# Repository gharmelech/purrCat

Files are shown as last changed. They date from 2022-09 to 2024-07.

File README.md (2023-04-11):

# **purrCat**

This is a novelty PCB Art of a purring cat.

Feel free to use this project or parts of it at will, but please give credit when doing so.

While this is an open source project, I am selling kits and assembled units for 10 and 15 USD respectivly.  
Please consider supporting us by [ordering here](https://forms.gle/wS7aRQJ3xb9KGsVB8).

## **Art**
The art was made by Taly Reznik - [@trollworks](https://www.instagram.com/trollworks/?fbclid=IwAR2XS3pt9mpKQIKOb-wqeVHk0iGZXp5bulvpvjSy-UH8qeWS0hPnVhlgy5U)  
Go check out her awesome work!

## **Hardware Description**
The project is based on TI's msp430fr2111 MCU. The current software could fit in (and easily compiled for) msp430fr2110 and could probably be further optimized to fit msp430fr2100, but going with the 2111 model leaves a lot of room for future expansion with just a small price difference.  

Purring is achived with a round radial vibration motor, which is low-side controlled with an nmos transistor.  
In addition, the eyes light up using reverse-mounted LEDs (might be worthwhile to change it to a side view LED in the future).  

Petting is detected using capacitive touch.  
There are 4 touch pads on the PCB, but only 1 is in use in the current FW.

### **Some FW details**

#### **Picky Cat!**
I wanted to make the cat as realistic as possible, so it only likes petting between 0.5 and 2Hz.  
(*Since I'm not doing swipe detection, it would also work with tapping. I might change it in a future version*)  
This is achived using a 2s sample buffer with 125ms slots. if the pad is touched for more than 3 slots in a row, the buffer zeroes.  
Furthermore, purring only starts after at least 1s of petting.

#### **Realistic Purring**
I have programmed a simple PWM function to make the vibration feel like real purring.  
It has dynamic change to the duty cycle, this creates the subtle ramp-up and ramp-down typical of a cat's purring.  
I tried a sinusoidal PWM function, but it didn't have the right feel to it.

#### **Programming and flashing**
The MCU is programmed using Code Composer Studio IDE.  
For software flashing I use a TI dev board LAUNCHPAD MSP-EXP430FR2433, which is the lowest cost programmer option available, though I assume you could make a flashing device out of an arduino.  
I left 3x2mm pitch pads for programming right near the MCU.  
They are arranged (from top to bottom) GND-SBWTCK-SBWTDIO, an additional connection to VCC is required and could be obtained from the battery clip.

### **Power Consumption**
The FW used to feature a distinct power saving mode, but changing the wait timer to RTC with VLO clock source randered that mode as unnedded.  
It is still available in code using a #define flag.

In the current configuration, sampling consumes about 2 micro Ampere - around 60uW at nominal 3V.  
When Purring, i.e. when the motor and the LEDs are enabled, the current consumption is about 22mA - 66mW at nonminal 3V.

The final design uses a cr2032 lithium cell which are rated at about 240mAh.  
While theoretical battery life should have been roughly 8 hours of purring or about 6 years of idle,  
The 240mAh rating is given at much lower current draw than that of the active purring.  
At 20mA, most cr2032 have a capacity of a mere 10-15mAh, giving only about 30 minutes of active purring.

I don't have a good explantion for it, but idle time also seems to substencialy lower than the theoretical - getting to around one week.

Note that this is not linear and even a small reduction in current draw while purring would result in longer operation time.  
Sadly, I was'nt able to find a way to reduce to consumption enough.

#### **LiPo mod**
Giving the poor battery life, I designed a small PCB holding an LDO and a charge connector for a LiPo, to be soldered instead of the battery clip.
The thought of using a LiPo crossed my mind several times, but I deemed it unvaiabel because of cost and required PCB space for a charge controller.
Finally, I had the realization to use a generic LiPo charger externaly (which could be obtained from AliExpress for very cheap) instead of making it onboard.
I did changed the current select resistor on the charger such that the max charge current will be 100 mA - suitable for the tiny LiPo I use.

I decided to use a 501015 60mAh battery.
Because these are rated at 1C, we get a runtime much closer to the theoretical value - about 1.5 hours of purring!
I have used a sub-optimal LDO with 30 uA quiescent current, which becomes the dominant current draw during idle.
I calculated arround 40 days of idle time, but have not ran this long time test yet.

### **Parts List**
- MCU: msp430fr2111
- LED: 2x 0805 LED (reverse mounted, color of your choice)
- Capacitors: 2x0805 10uF MLCC (1 for the MCU and 1 for the Motor), 1x0603 100nF MLCC (for the MCU)
- Resistors: 3x0603 1k Ohm (current limiting for the transistor and the LEDs), 1x0603 100k Ohm (pulldown for the transistor, could be omitted as the driver pin is push-pull)
- Diode: 1x0603 schottky diode (I used Kyocera AVX SD0603S040S0R2)
- Transistor: 1xSOT3 NMOS Transistor (I used Nexperia NXV55UNR)
- Battery clip: 1x Keystone 3034 (cr2032 battery holder), note that not all battery holders can fit in the PCBs footprint)
- Vibration motor: 1x 10mm round radial vibration motor(or smaller), note that there are no pads for soldering it. one lead should be connected to vcc(I used the cap for it) and the other to the transistor drain pin (I made a bigger pad to accomodate this).

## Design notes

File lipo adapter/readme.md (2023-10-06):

The lipo adapter is designed to replace the battery holder
it holds an LDO, connector for an external charger and pads for the lipo

Since it is a very simple board, I designed it using the easyEDA online suite.
I recomend manufacturing it as thin as possiable.

For the LDO, I used TLV74333PDBVR, but a more efficiant model would be preferable

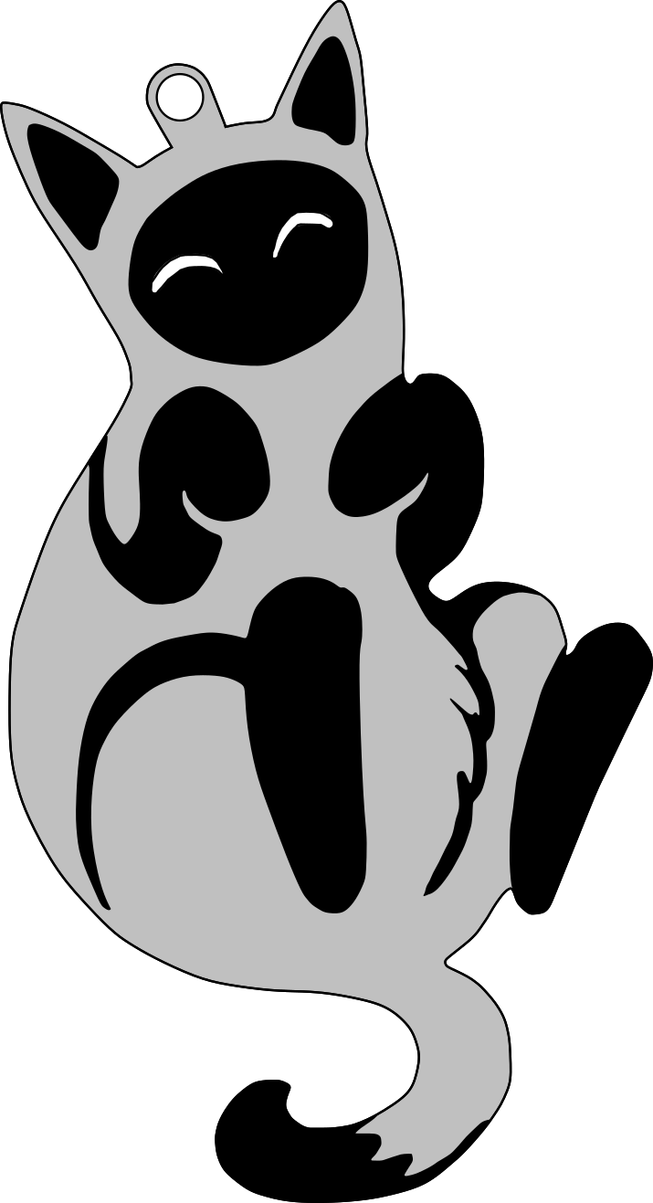
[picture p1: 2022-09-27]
Art/template.png

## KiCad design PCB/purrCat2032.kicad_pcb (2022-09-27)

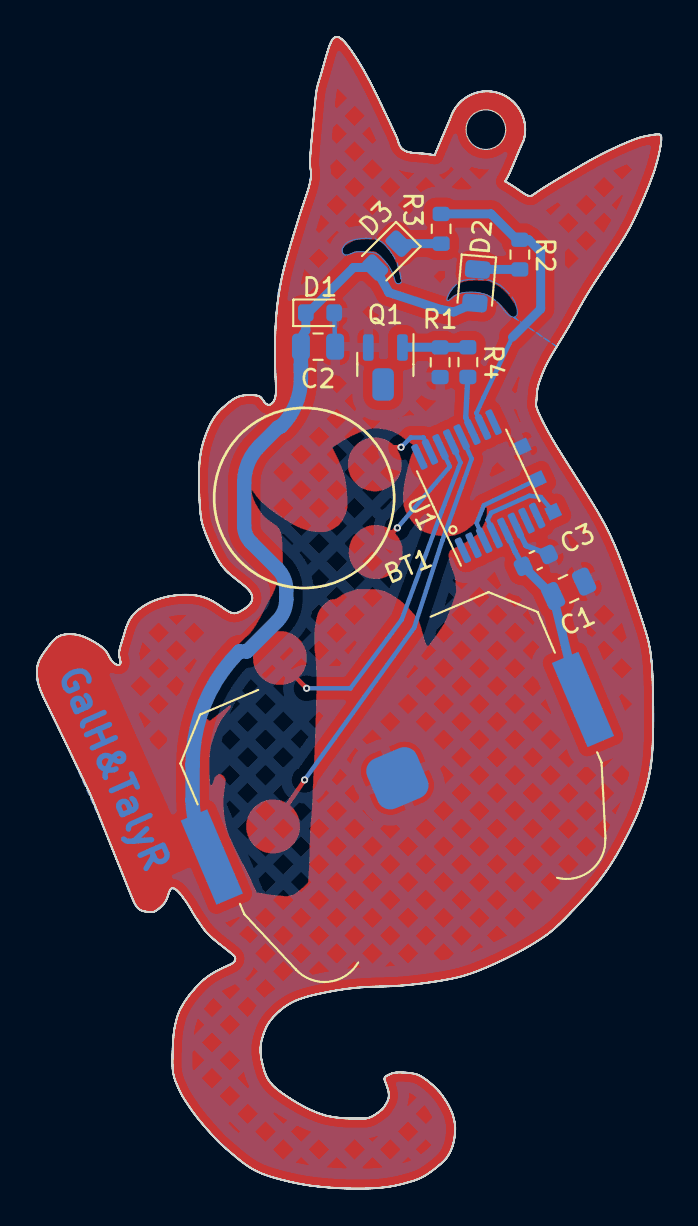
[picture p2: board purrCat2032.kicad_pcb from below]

Board: 2 copper layers, 34.7 x 64.0 mm, 14 parts (13 on the bottom side), 7 nets.

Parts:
BT1: Battery_Cell; BatteryHolder_Keystone_3034_1x20mm
C1, C2: 10u; C_0805_2012Metric
C3: 100n; C_0603_1608Metric
D1: D_Schottky; D_0603_1608Metric
D2, D3: LED; LED_0805_2012Metric
Q1: Q_NMOS_GSD; SOT-23
R1: 100k; R_0603_1608Metric
R2, R3, R4: 1k; R_0603_1608Metric
Ref**: Val**; biggerCat_kicad_layers
U1: MSP430FR2110/MSP430FR2111; TSSOP-16_4.4x5mm_P0.65mm

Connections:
/GND: BT1.2 (-), C1.2, C2.2, C3.2, D1.2 (A), Q1.2 (S), R1.2, U1.6 (DVSS)
/LED1_R: D2.1 (K), R2.1
/LED2_R: D3.1 (K), R3.1
/LED_MCU: R2.2, R3.2, U1.10 (P2.0/TB0.1/COUT)
/MOTOR_MCU: R4.2, U1.11 (P1.7/UCA0TXD/UCA0SIMO/TB0.2/TDO/A7/VREF+)
/MOTOR_MCU_R: Q1.1 (G), R1.1, R4.1
/V_BAT: BT1.1 (+), C1.1, C2.1, C3.1, D1.1 (K), D2.2 (A), D3.2 (A), U1.5 (DVCC)

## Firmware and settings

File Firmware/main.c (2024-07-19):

/*purrCat - a purring cat PCB by Gal Harmelech
 * I wanted to make this cat as picky as a real cat, so it does not purr for any type of petting:
 * The main principle is a 2 seconds buffer with 250 ms slots, this enables identifying "petting" between 0.5 to 4 Hz
 * If being petted with an acceptable pattern for more than 1 second - It will start purring.
 * For the Purring there is a 40 Hz PWM function with 0.25 to 0.33 duty cycle dynamically changing to give the small ramp-up and down in a cat's purring
 * The eyes just light up whenever it is purring, but more sophisticated schemes are possible as the eyes are wired to the second timer output
 * Feel free to improve and expend this software, I'm curious to see what the community could do with it!
 * My one request is that you do not remove my name from it
 * Have Fun!
 * 
 * Some parts of the software are based on TI's example code, for those parts the following is applicable:
 * 
 * --COPYRIGHT--,BSD_EX
 * Copyright (c) 2014, Texas Instruments Incorporated
 * All rights reserved.
 *
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
 * *  Redistributions of source code must retain the above copyright
 *    notice, this list of conditions and the following disclaimer.
 *
 * *  Redistributions in binary form must reproduce the above copyright
 *    notice, this list of conditions and the following disclaimer in the
 *    documentation and/or other materials provided with the distribution.
 *
 * *  Neither the name of Texas Instruments Incorporated nor the names of
 *    its contributors may be used to endorse or promote products derived
 *    from this software without specific prior written permission.
 *
 * THIS SOFTWARE IS PROVIDED BY THE COPYRIGHT HOLDERS AND CONTRIBUTORS "AS IS"
 * AND ANY EXPRESS OR IMPLIED WARRANTIES, INCLUDING, BUT NOT LIMITED TO,
 * THE IMPLIED WARRANTIES OF MERCHANTABILITY AND FITNESS FOR A PARTICULAR
 * PURPOSE ARE DISCLAIMED. IN NO EVENT SHALL THE COPYRIGHT OWNER OR
 * CONTRIBUTORS BE LIABLE FOR ANY DIRECT, INDIRECT, INCIDENTAL, SPECIAL,
 * EXEMPLARY, OR CONSEQUENTIAL DAMAGES (INCLUDING, BUT NOT LIMITED TO,
 * PROCUREMENT OF SUBSTITUTE GOODS OR SERVICES; LOSS OF USE, DATA, OR PROFITS;
 * OR BUSINESS INTERRUPTION) HOWEVER CAUSED AND ON ANY THEORY OF LIABILITY,
 * WHETHER IN CONTRACT, STRICT LIABILITY, OR TORT (INCLUDING NEGLIGENCE OR
 * OTHERWISE) ARISING IN ANY WAY OUT OF THE USE OF THIS SOFTWARE,
 * EVEN IF ADVISED OF THE POSSIBILITY OF SUCH DAMAGE.
 *
 *******************************************************************************
 *
 *                       MSP430 CODE EXAMPLE DISCLAIMER
 *
 * MSP430 code examples are self-contained low-level programs that typically
 * demonstrate a single peripheral function or device feature in a highly
 * concise manner. For this the code may rely on the device's power-on default
 * register values and settings such as the clock configuration and care must
 * be taken when combining code from several examples to avoid potential side
 * effects. Also see www.ti.com/grace for a GUI- and www.ti.com/msp430ware
 * for an API functional library-approach to peripheral configuration.
 *
 * --/COPYRIGHT--*/
//******************************************************************************

#include <msp430.h>
#include <stdint.h>
#include <stdbool.h>

/*Time constants*/
#define WDT_meas_setting (WDT_MDLY_0_5)             // Defines WDT SMCLK interval for sensor measurements with duration of 0.5 ms
#define SAMPLE_PERIOD (125)                         // Time between samples in ms

/*Idle Mode*/
//#define USE_IDLEMODE
#ifdef USE_IDLEMODE
#define ACTIVE_TIME 10                              // Time to stay active before entering idle mode (sec)
#define IDLE_LIMIT (ACTIVE_TIME<<2)
#define IDLE_SAMPLE_PERIOD (1500)                   // Time between samples when in idle mode (ms)
#endif

/* Sensor settings*/
#define KEY_LVL     (750)                           // Defines threshold for a key press
/*Set to ~ half the max delta expected*/

/*Outputs*/
#define LED                 (BIT0)                  // P2.0 LED output
#define MOTOR               (BIT7)                  // P1.7 Vibration motor output

/*Touch Pads*/
#define TOUCHPAD_1          (BIT6)                  // P1.6 Touchpad
#define CAPTURE_TOUCHPAD_1   (CAPTIOEN + CAPTIOPOSEL0 + CAPTIOPISEL_6)
#define TOUCHPAD_2          (BIT5)                  // P1.5 Touchpad
#define CAPTURE_TOUCHPAD_2   (CAPTIOEN + CAPTIOPOSEL0 + CAPTIOPISEL_5)
#define TOUCHPAD_3          (BIT4)                  // P1.4 Touchpad
#define CAPTURE_TOUCHPAD_3   (CAPTIOEN + CAPTIOPOSEL0 + CAPTIOPISEL_4)
#define TOUCHPAD_4          (BIT3)                  // P1.3 Touchpad
#define CAPTURE_TOUCHPAD_4   (CAPTIOEN + CAPTIOPOSEL0 + CAPTIOPISEL_3)

// Global variables for sensing
unsigned int base_cnt, meas_cnt;
int delta_cnt;
uint16_t pressBuffer = 0;
uint8_t outputEnable = 0;
uint8_t dutyCounts [] = {200, 200, 255, 255, 255};
uint8_t dutyIndex = 0;
#ifdef USE_IDLEMODE
uint8_t idleCnt = 0;
#endif
/* System Routines*/
void measure_count(void);                           // Measures each capacitive sensor
void startPWM(void);
void stopPWM(void);

int main(void)
{
    unsigned int i;
    WDTCTL = WDTPW + WDTHOLD;                       // Stop watchdog timer
    SFRIE1 |= WDTIE;                                // enable WDT interrupt
    P1DIR = 0xff;
    P2DIR = 0xff;
    P1OUT = 0x0;
    P2OUT = LED;
    PM5CTL0 &= ~LOCKLPM5;
    __bis_SR_register(GIE);                         // Enable interrupts
    measure_count();                                // Establish baseline capacitance
    base_cnt = meas_cnt;
    for(i=15; i>0; i--)                             // Repeat and avg base measurement
    {
        measure_count();
        base_cnt = (meas_cnt+base_cnt)>>1;
    }
    /* Main loop starts here*/
    while (1)
    {
        pressBuffer = (pressBuffer << 1);           // Advance sliding window
        if (pressBuffer == 0)
            outputEnable = 0;
        measure_count();
        delta_cnt = base_cnt - meas_cnt;            // Calculate delta: c_change
        if (delta_cnt < 0)                          // If negative: result increased
        {                                           // beyond baseline, i.e. cap dec
            base_cnt = (base_cnt+meas_cnt) >> 1;    // Re-average quickly
            delta_cnt = 0;                          // Zero out for pos determination
        }
        else if (delta_cnt > KEY_LVL)               // Touch detected
        {
#ifdef USE_IDLEMODE
            idleCnt = 0;
#endif
            if ((pressBuffer & 0x0006) == 0x0006)   // Two previous slots had a press --> stop output and reset buffer
            {
                pressBuffer = 0;
                outputEnable = 0;
            }
            else
            {
                pressBuffer +=1;                    // push
                if (pressBuffer > 0x7F)
                    outputEnable = 1;
            }
        }
        else                                        // No Touch detected
        {
            base_cnt = base_cnt - 1;                // Account for capacitance drift
#ifdef USE_IDLEMODE
            if (idleCnt < IDLE_LIMIT)
                idleCnt++;
#endif
        }
        if (outputEnable == 1)
        {
            startPWM();
            P2OUT &= (~LED);
        }
        else
        {
            stopPWM();
            P2OUT |= LED;
        }
        RTCMOD = SAMPLE_PERIOD-1;
#ifdef USE_IDLEMODE
        if (idleCnt == IDLE_LIMIT)
            RTCMOD = IDLE_SAMPLE_PERIOD-1;
#endif
        RTCCTL |= RTCSS__VLOCLK | RTCSR |RTCPS__10;
        RTCCTL |= RTCIE;
        __bis_SR_register(LPM4_bits);
    }
}                                                   // End Main

/* Measure count result (capacitance)*/
void measure_count(void)
{
    TB0CTL = TBSSEL_3 + MC_2;                       // INCLK, cont mode
    TB0CCTL1 = CM_3 + CCIS_2 + CAP;                 // Pos&Neg,GND,Cap
    /*Configure Ports for relaxation oscillator*/
    CAPTIOCTL |= CAPTURE_TOUCHPAD_3;                //Only using touchpad #3, in future could create more elaborate functions using the other pads
    /*Setup Gate Timer*/
    WDTCTL = WDT_meas_setting;                      // WDT, ACLK, interval timer
    TB0CTL |= TBCLR;                                // Clear Timer_B TBR
    __bis_SR_register(LPM0_bits+GIE);               // Wait for WDT interrupt
    TB0CCTL1 ^= CCIS0;                              // Create SW capture of CCR1
    meas_cnt = TB0CCR1;                             // Save result
    WDTCTL = WDTPW + WDTHOLD;                       // Stop watchdog timer
    CAPTIOCTL = 0;
}
void startPWM(void)
{
    TB0CCR0 = 900-1;                                // PWM Freq 32.768kHz divided by TB0CCR0
    dutyIndex++;
    if (dutyIndex > 4)
        dutyIndex = 0;
    TB0CCR2 = dutyCounts[(uint8_t)(dutyIndex)];     // CCR2 PWM duty cycle TB0CCR2/TB0CCR0
    TB0CCTL2 = OUTMOD_7;                            // CCR2 reset/set
    TB0CTL = TBSSEL__ACLK | MC__UP | TBCLR;         // ACLK, up mode, clear TAR
    P1SEL1 |= MOTOR;                                // Configure Motor output to Timer B 0.2
    PM5CTL0 &= ~LOCKLPM5;
}
void stopPWM(void)
{
    TB0CTL = TBSSEL__ACLK | MC__STOP | TBCLR;       // ACLK, stop mode, clear TAR
    P1SEL1 &= ~(MOTOR);
}

/* Watchdog Timer interrupt service routine*/
#if defined(__TI_COMPILER_VERSION__) || defined(__IAR_SYSTEMS_ICC__)
#pragma vector=WDT_VECTOR
__interrupt void watchdog_timer(void)
#elif defined(__GNUC__)
void __attribute__ ((interrupt(WDT_VECTOR))) watchdog_timer (void)
#else
#error Compiler not supported!
#endif
{
    TB0CCTL1 ^= CCIS0;                              // Create SW capture of CCR1
    __bic_SR_register_on_exit(LPM4_bits);           // Exit LPM4 on reti
}

/*RTC ISR*/
#if defined(__TI_COMPILER_VERSION__) || defined(__IAR_SYSTEMS_ICC__)
#pragma vector=RTC_VECTOR
__interrupt void RTC_ISR(void)
#elif defined(__GNUC__)
void __attribute__ ((interrupt(RTC_VECTOR))) RTC_ISR (void)
#else
#error Compiler not supported!
#endif
{
    TB0CCTL1 ^= CCIS0;                              // Create SW capture of CCR1
    RTCCTL = RTCSS__DISABLED;
    __bic_SR_register_on_exit(LPM4_bits);
}

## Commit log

2022-07-02 Led turn on with purr
2022-09-23 idle power optimization
2022-09-27 PCB files upload
    PCB files and schematics along with library for the unique footprints
    [holding_frame-B_Cu.gbr, holding_frame-B_Mask.gbr, holding_frame-B_Paste.gbr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]
2022-09-27 Art Upload
    Original art and svg with layers for footprint creation
2022-10-09 Battery life test bench
2022-10-13 sample power optimization
    Change wait between samples to use RTC with VLO rather than watchdog --> resulted in ~2uA power consumption.
    Reduced sample power consumption renders the idle mode redundant, so it is disabled using a parameter
2023-03-21 change sampling slot size, documentation, switch magic numbers to define
